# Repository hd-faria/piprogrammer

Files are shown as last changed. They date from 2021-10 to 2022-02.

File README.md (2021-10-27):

# piprogrammer
This hat was designed based on Wren's Pi400-Pico-Plate, but since I don't have a Pi400, just a Raspberry Pi 4 4GB, I needed to make some changes. Also added an extra button and a JST(Qwiic) connector, which is connected to floating header because I wanted the flexibility to move I2C. Also added a 50" JTAG/SWD header footprint in hopes that I can use the Pi4 to program target devices other than RP2040 based boards, I remember to have seem some adafruit/learn post on this kind of subject some time ago.

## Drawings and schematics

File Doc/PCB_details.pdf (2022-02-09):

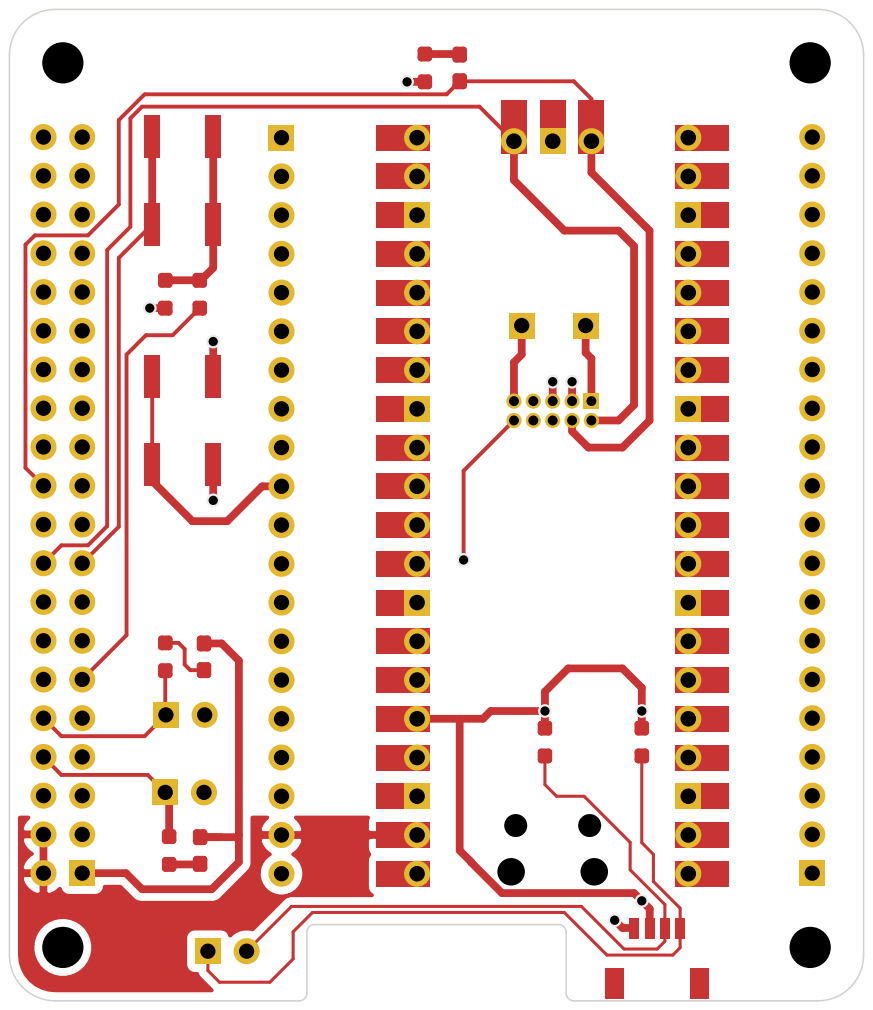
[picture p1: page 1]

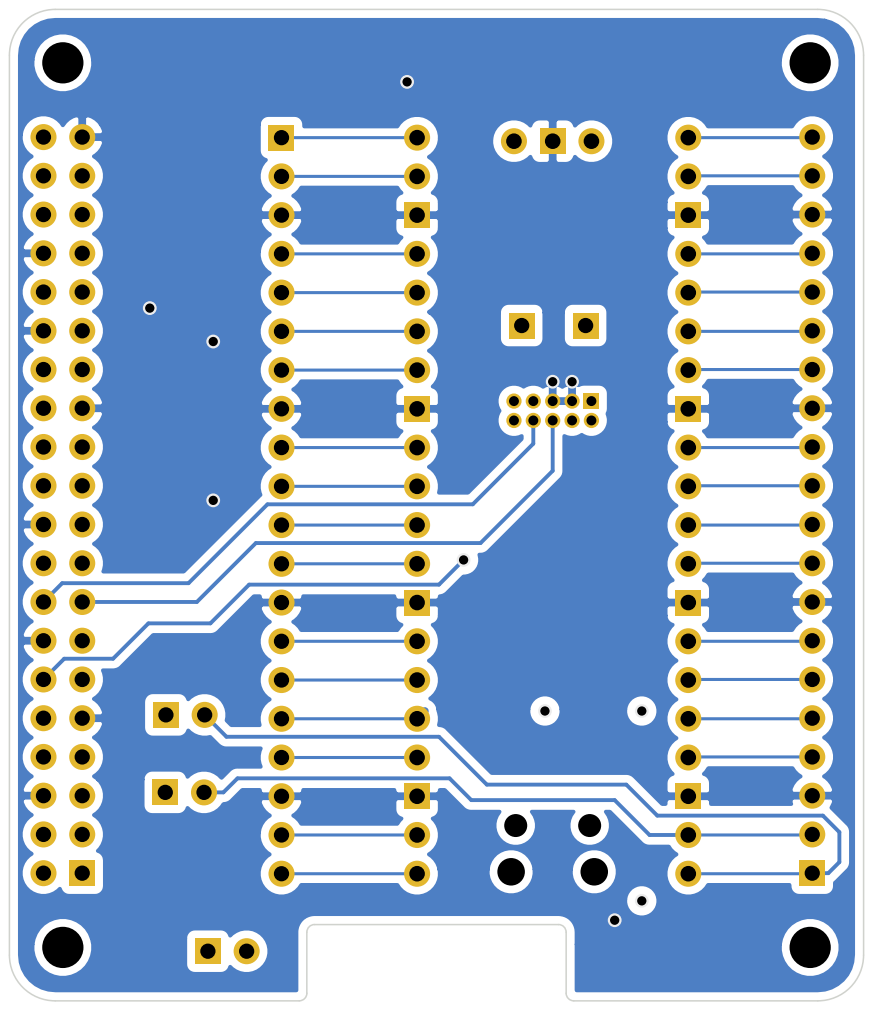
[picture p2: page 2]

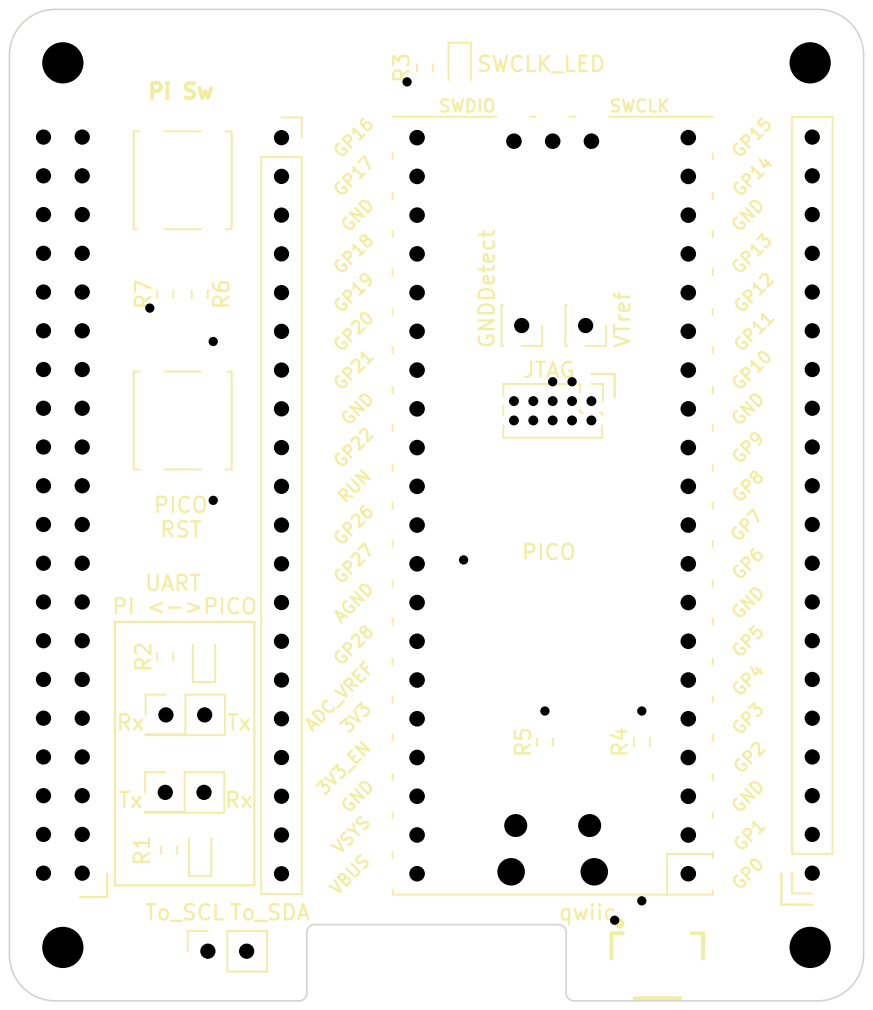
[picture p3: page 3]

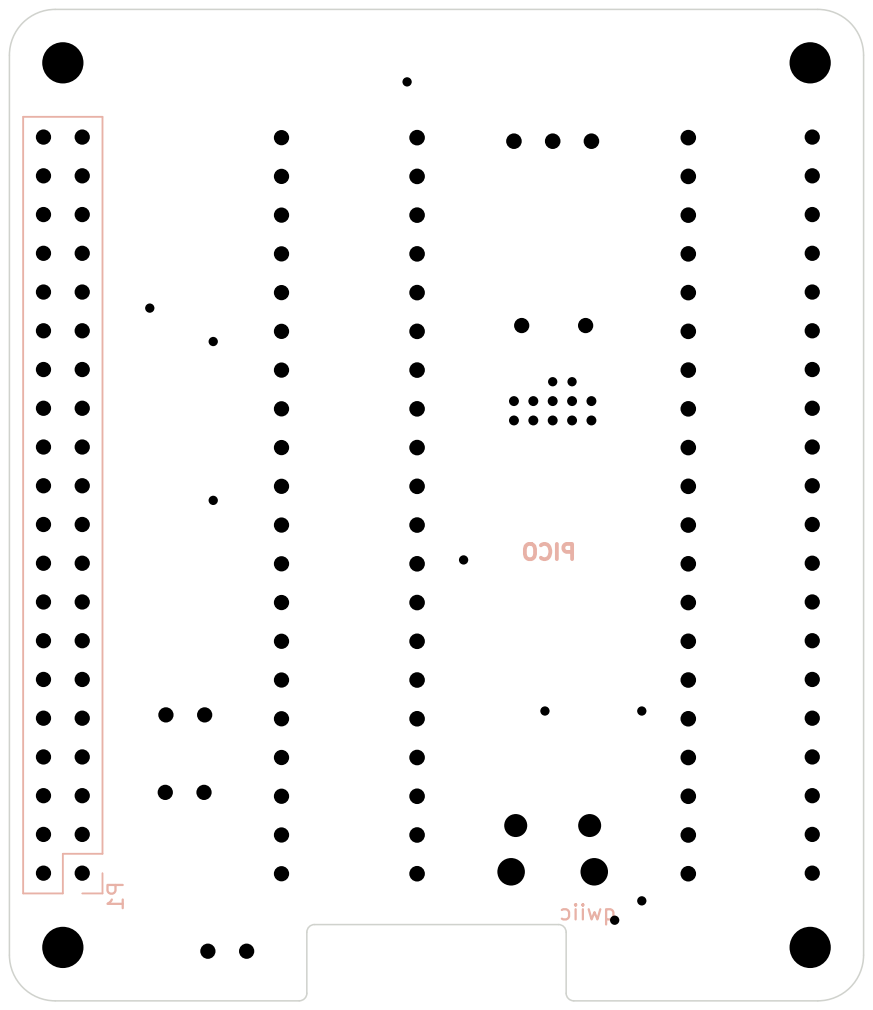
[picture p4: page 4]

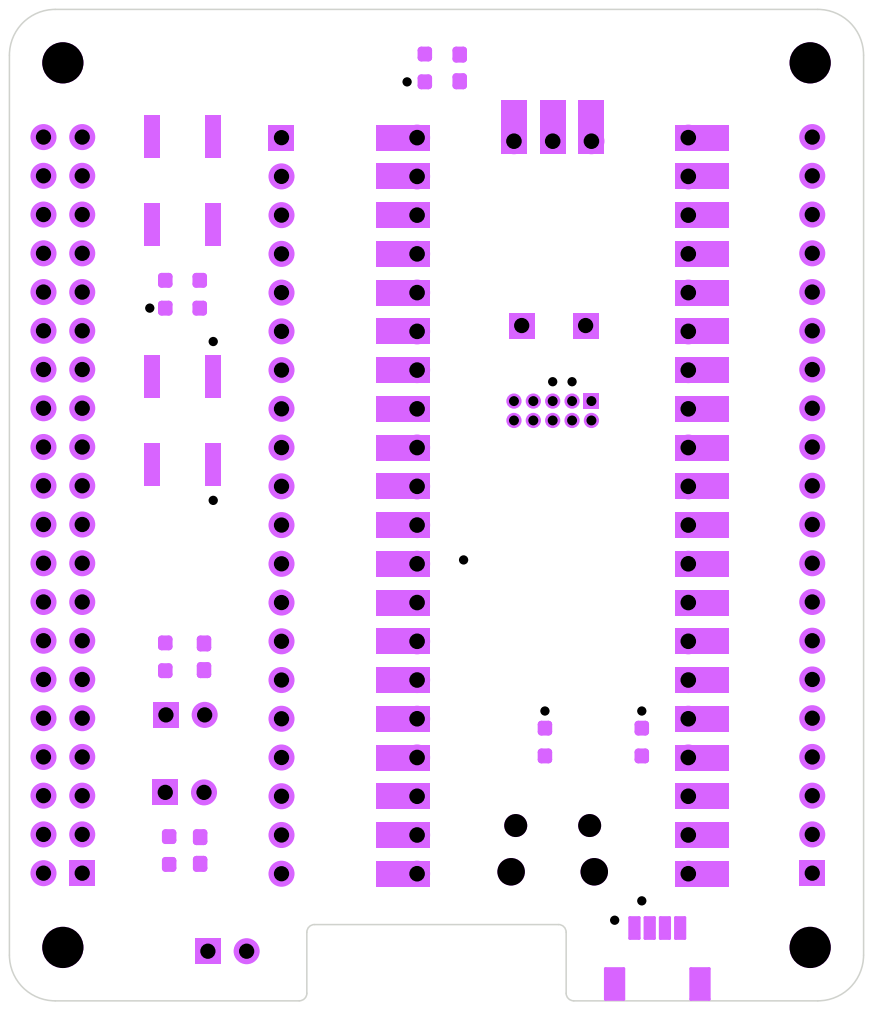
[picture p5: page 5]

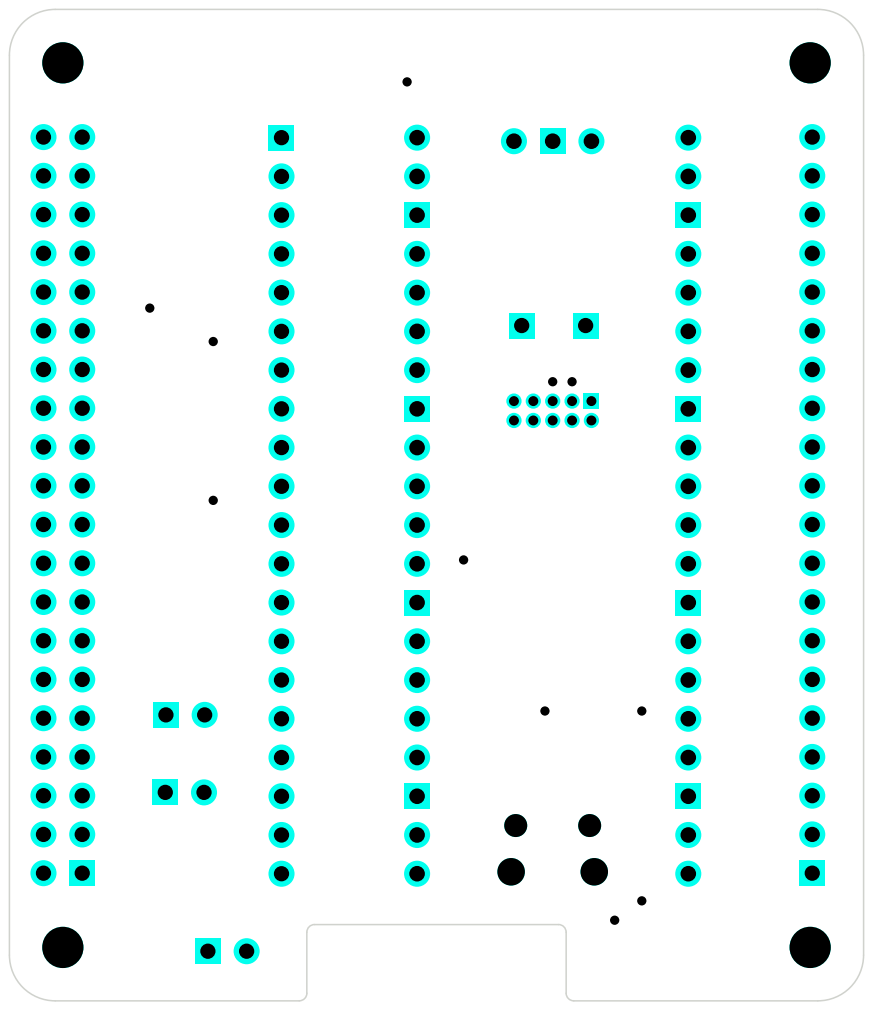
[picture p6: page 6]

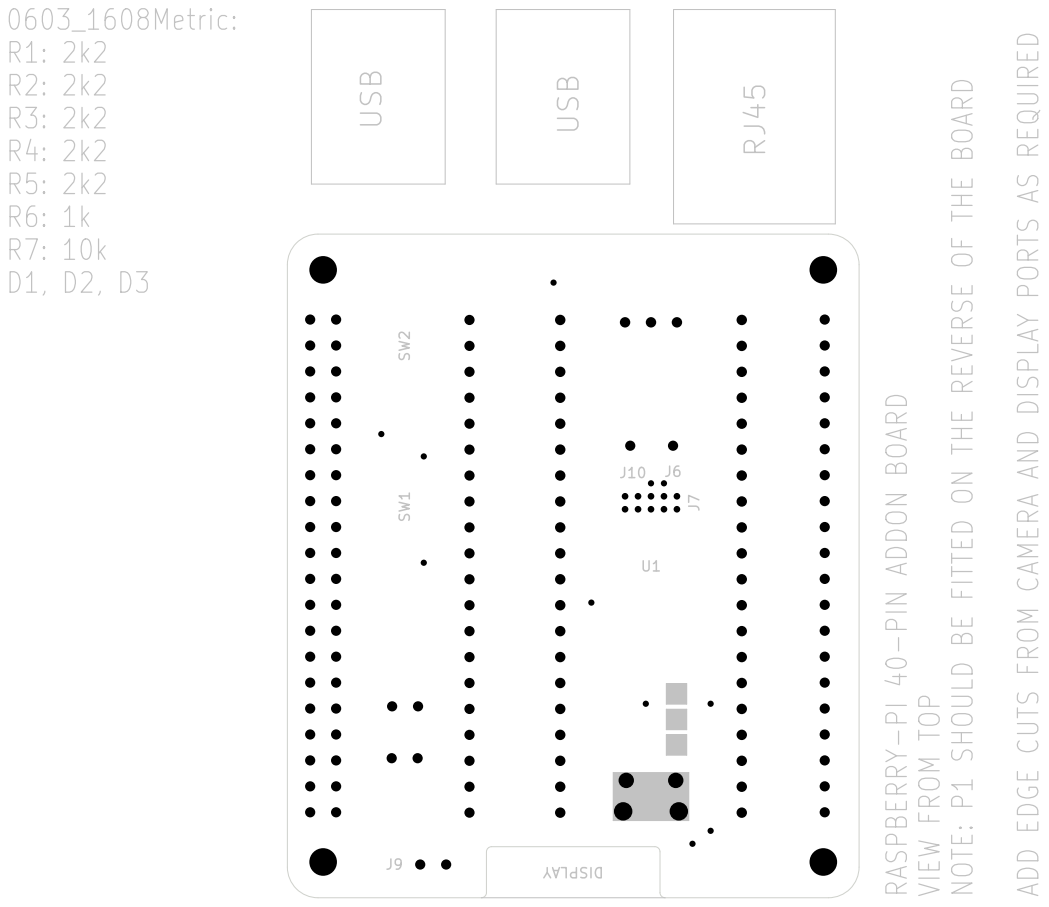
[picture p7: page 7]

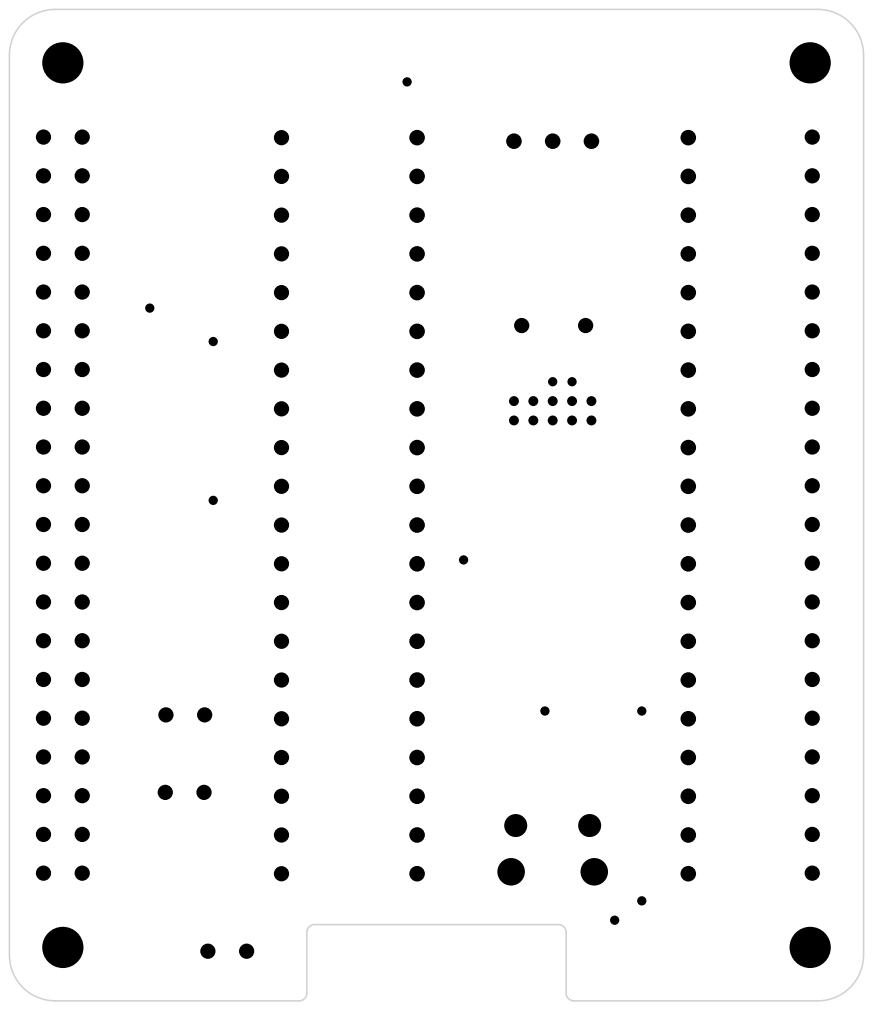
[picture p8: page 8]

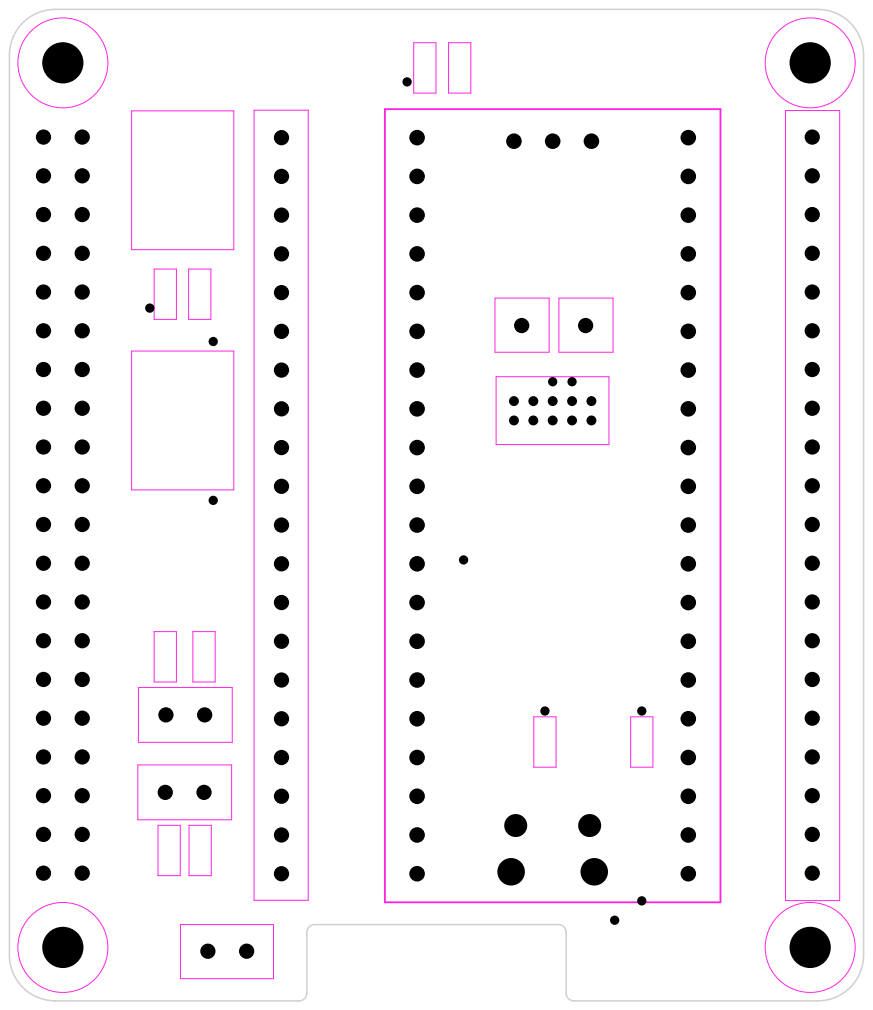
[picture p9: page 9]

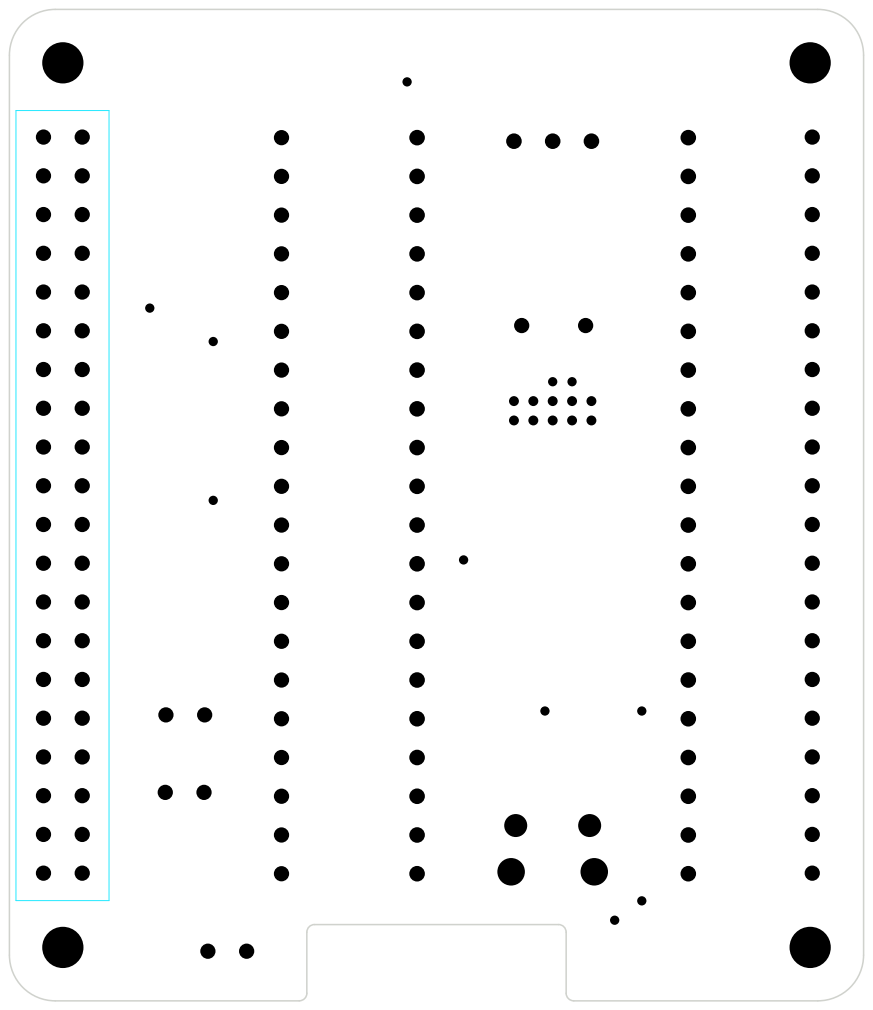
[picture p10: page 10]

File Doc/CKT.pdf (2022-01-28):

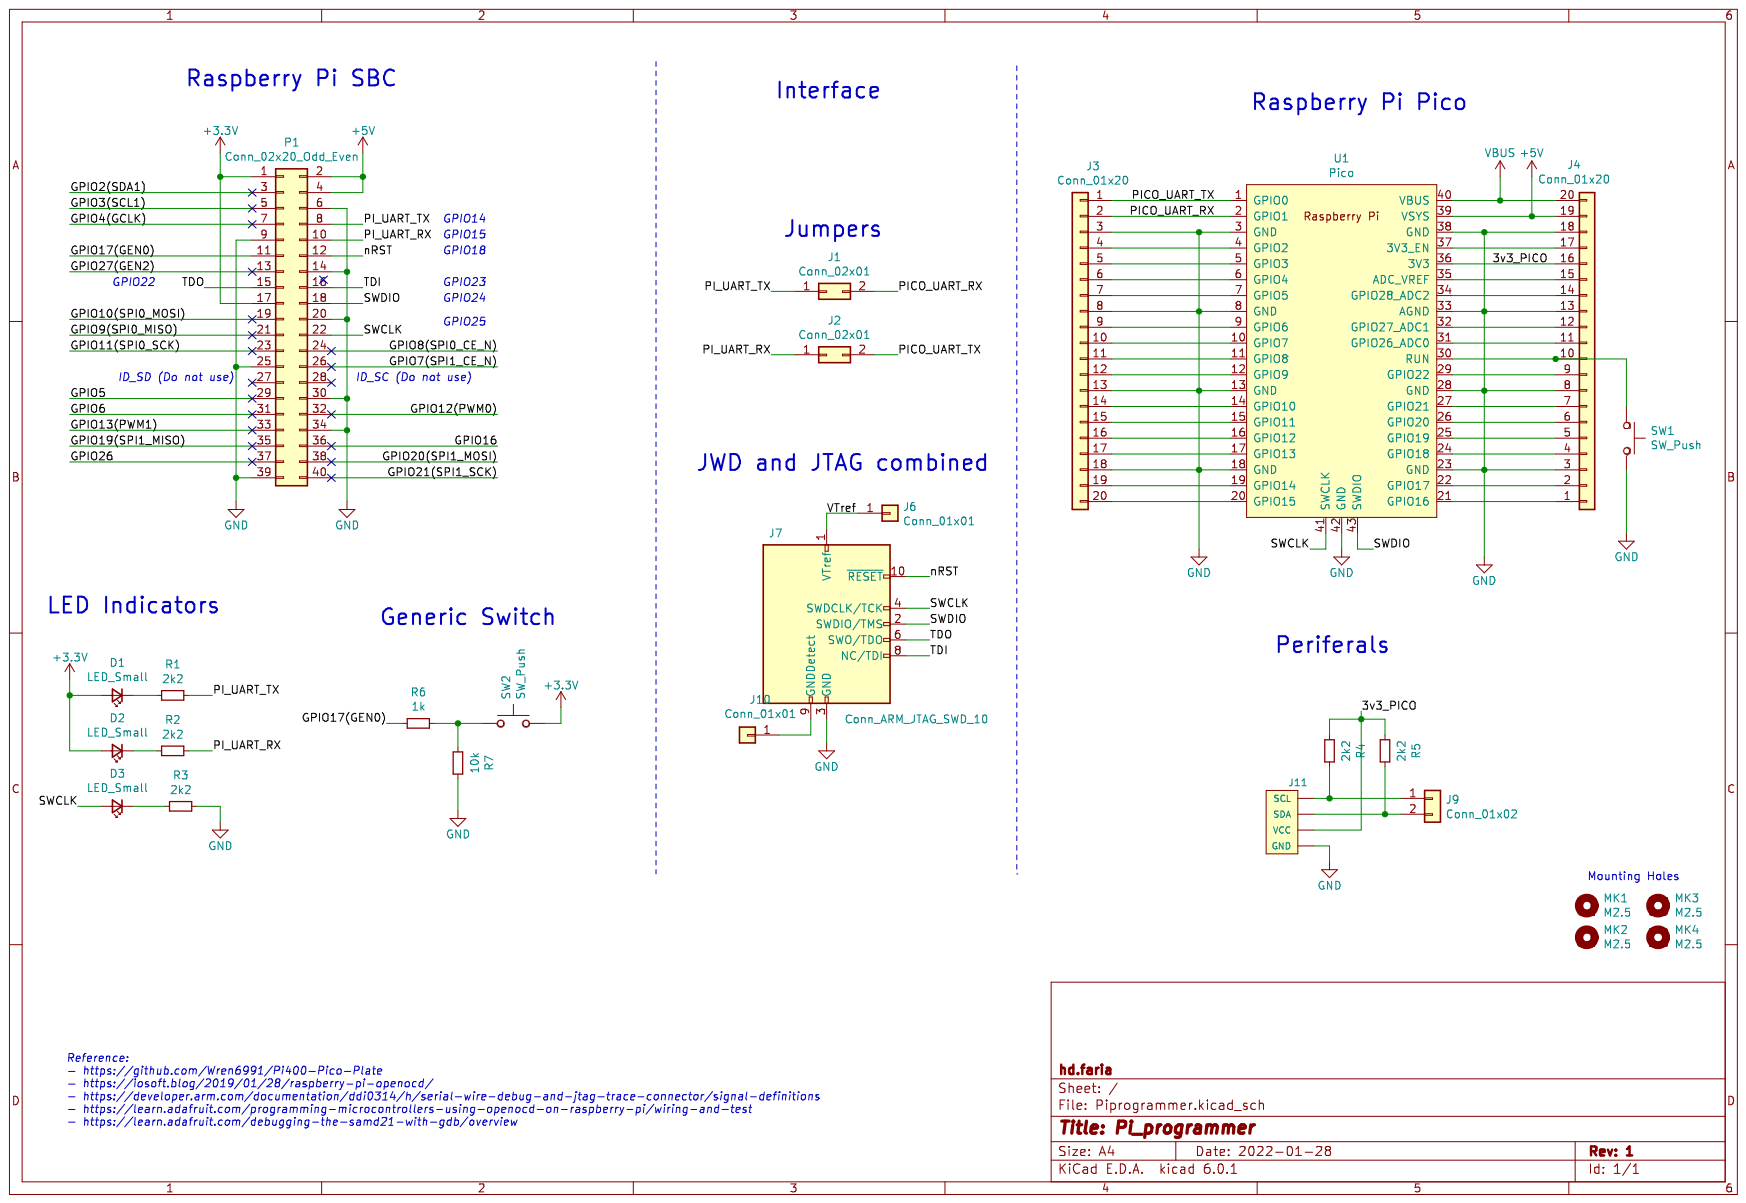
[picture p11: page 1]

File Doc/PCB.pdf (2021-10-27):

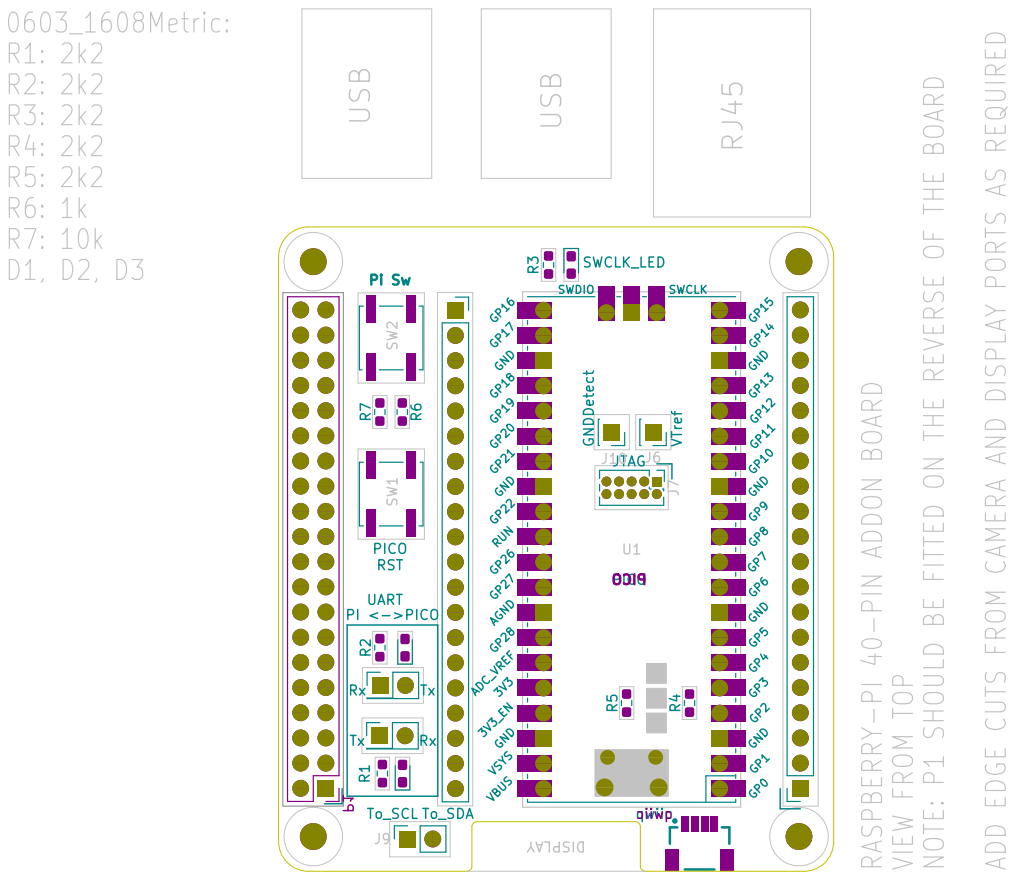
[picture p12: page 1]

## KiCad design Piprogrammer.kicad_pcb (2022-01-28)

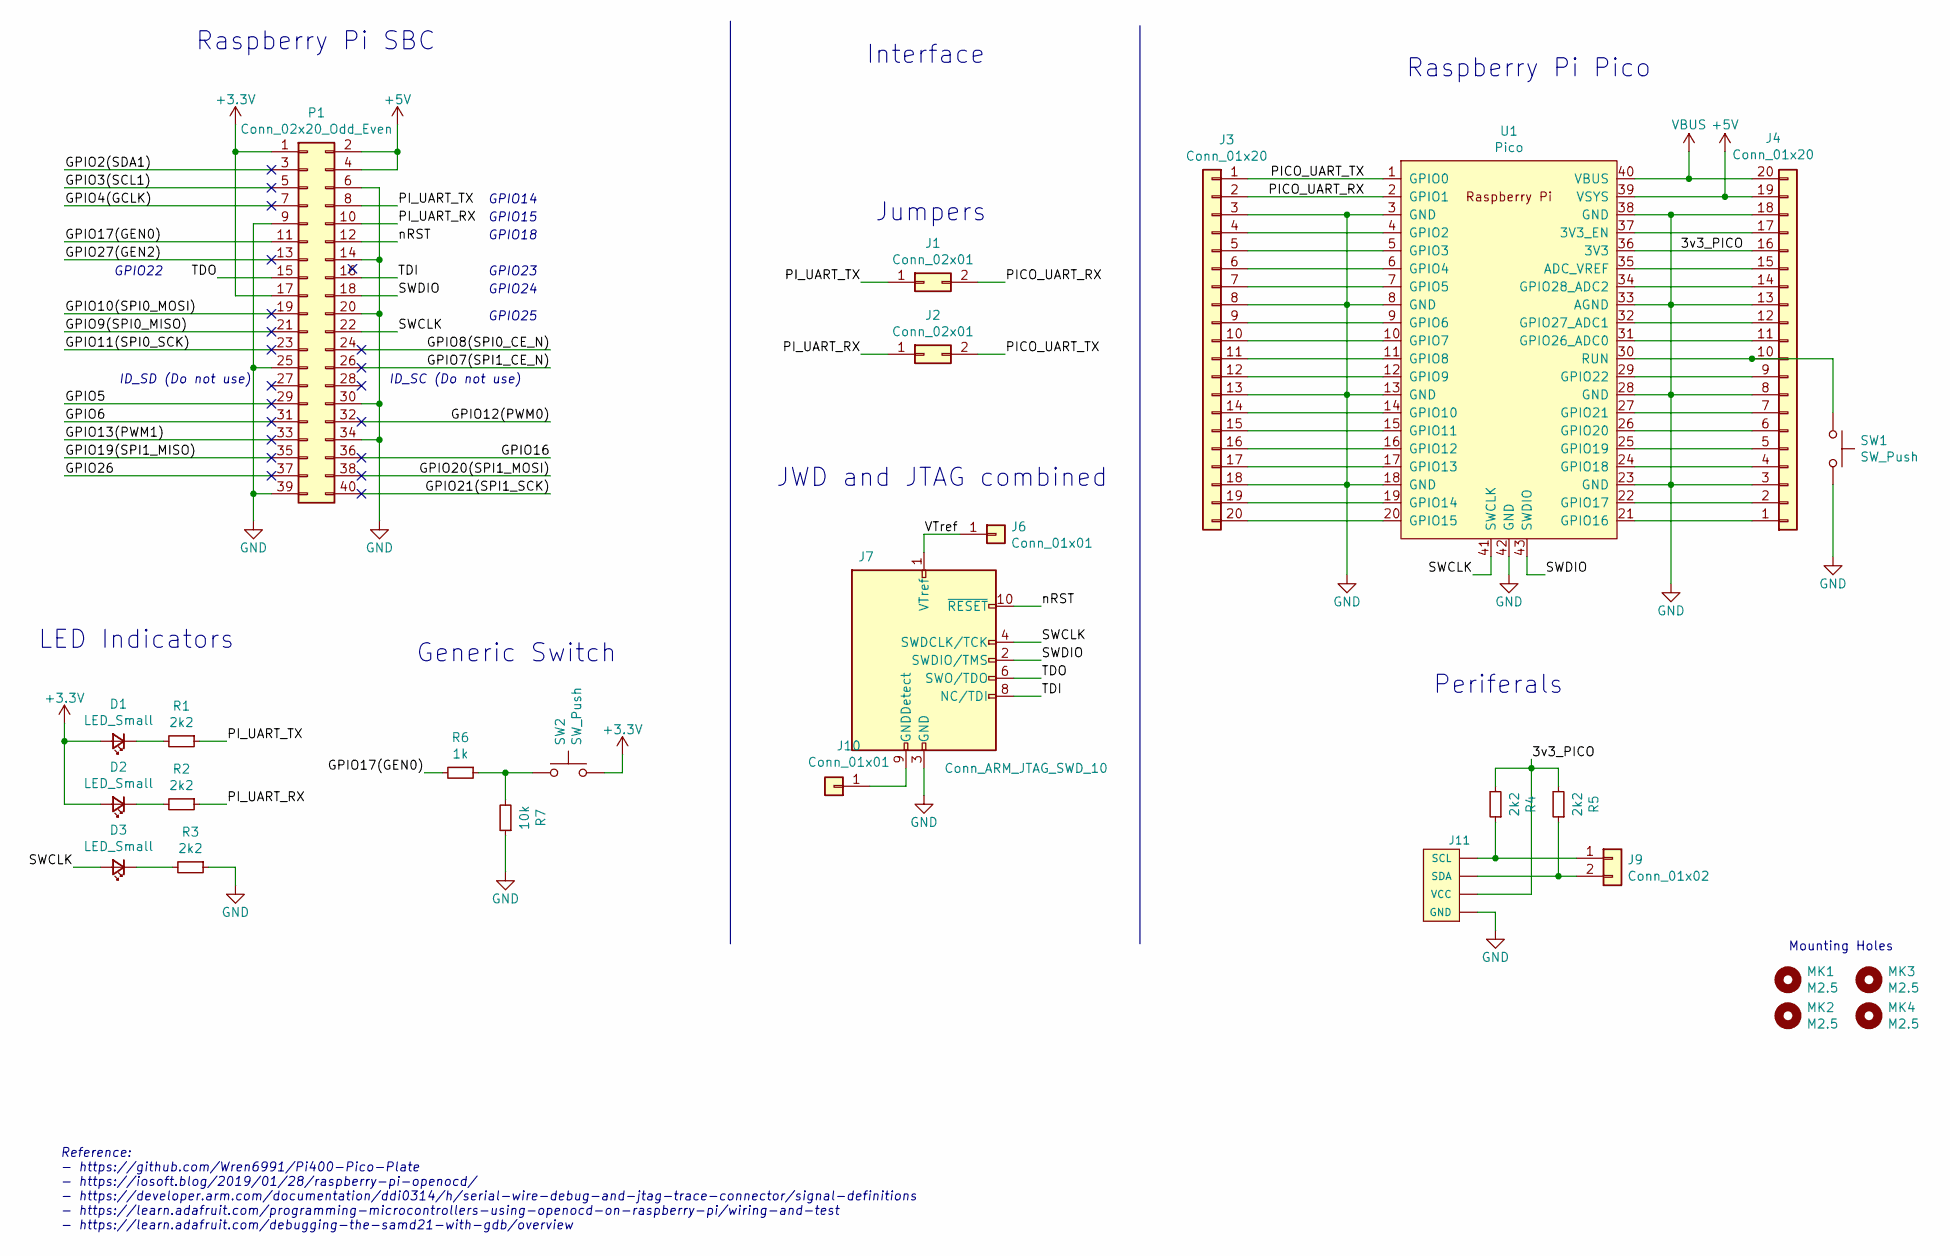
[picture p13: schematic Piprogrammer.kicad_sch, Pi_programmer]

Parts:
D1, D2, D3: LED_Small; LED_0603_1608Metric_Pad1.05x0.95mm_HandSolder
J1, J2: Conn_02x01; PinHeader_2x01_P2.54mm_Vertical
J3, J4: Conn_01x20; PinSocket_1x20_P2.54mm_Vertical
J6, J10: Conn_01x01; PinSocket_1x01_P2.54mm_Vertical
J7: Conn_ARM_JTAG_SWD_10; PinHeader_2x05_P1.27mm_Vertical
J9: Conn_01x02; PinSocket_1x02_P2.54mm_Vertical
J11: QWIIC_CONNECTORJS-1MM; 1X04_1MM_RA
MK1, MK2, MK3, MK4: M2.5; MountingHole_2-5mm
P1: Conn_02x20_Odd_Even; Socket_Strip_Straight_2x20
R1, R2, R3, R4, R5: 2k2; R_0603_1608Metric_Pad0.98x0.95mm_HandSolder
R6: 1k; R_0603_1608Metric_Pad0.98x0.95mm_HandSolder
R7: 10k; R_0603_1608Metric_Pad0.98x0.95mm_HandSolder
SW1, SW2: SW_Push; SW_Push_1P1T_NO_CK_KSC6xxJ
U1: Pico; RPi_Pico_SMD_TH

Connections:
+3V3: D1.2 (A), D2.2 (A), P1.1, P1.17, SW2.2
+5V: J4.19, P1.2, P1.4, U1.39 (VSYS)
/3v3_PICO: J4.16, J11.2 (VCC), R4.2, R5.2, U1.36 (3V3)
/GPIO2(SDA1): P1.3
/GPIO3(SCL1): P1.5
/GPIO4(GCLK): P1.7
/GPIO5: P1.29
/GPIO6: P1.31
/GPIO7(SPI1_CE_N): P1.26
/GPIO8(SPI0_CE_N): P1.24
/GPIO9(SPI0_MISO): P1.21
/GPIO10(SPI0_MOSI): P1.19
/GPIO11(SPI0_SCK): P1.23
/GPIO12(PWM0): P1.32
/GPIO13(PWM1): P1.33
/GPIO16: P1.36
/GPIO17(GEN0): P1.11, R6.2
/GPIO19(SPI1_MISO): P1.35
/GPIO20(SPI1_MOSI): P1.38
/GPIO21(SPI1_SCK): P1.40
/GPIO26: P1.37
/GPIO27(GEN2): P1.13
/PICO_UART_RX: J1.2, J3.2, U1.2 (GPIO1)
/PICO_UART_TX: J2.2, J3.1, U1.1 (GPIO0)
/PI_UART_RX: J2.1, P1.10, R2.1
/PI_UART_TX: J1.1, P1.8, R1.1
/SWCLK: D3.2 (A), J7.4 (SWDCLK/TCK), P1.22, U1.41 (SWCLK)
/SWDIO: J7.2 (SWDIO/TMS), P1.18, U1.43 (SWDIO)
/TDI: J7.8 (NC/TDI), P1.16
/TDO: J7.6 (SWO/TDO), P1.15
/VTref: J6.1, J7.1 (VTref)
/nRST: J7.10 (~RESET), P1.12
GND: J3.3, J3.8, J3.13, J3.18, J4.3, J4.8, J4.13, J4.18, J7.3 (GND), J7.5 (GND), J11.1 (GND), P1.6, P1.9, P1.14, P1.20, P1.25, P1.30, P1.34, P1.39, R3.1, R7.1, SW1.2, U1.3 (GND), U1.8 (GND), U1.13 (GND), U1.18 (GND), U1.23 (GND), U1.28 (GND), U1.33 (AGND), U1.38 (GND), U1.42 (GND)
unnamed: D1.1 (K), R1.2
unnamed: D2.1 (K), R2.2
unnamed: D3.1 (K), R3.2
unnamed: J3.4, U1.4 (GPIO2)
unnamed: J3.5, U1.5 (GPIO3)
unnamed: J3.6, U1.6 (GPIO4)
unnamed: J3.7, U1.7 (GPIO5)
unnamed: J3.9, U1.9 (GPIO6)
unnamed: J3.10, U1.10 (GPIO7)
unnamed: J3.11, U1.11 (GPIO8)
unnamed: J3.12, U1.12 (GPIO9)
unnamed: J3.14, U1.14 (GPIO10)
unnamed: J3.15, U1.15 (GPIO11)
unnamed: J3.16, U1.16 (GPIO12)
unnamed: J3.17, U1.17 (GPIO13)
unnamed: J3.19, U1.19 (GPIO14)
unnamed: J3.20, U1.20 (GPIO15)
unnamed: J4.1, U1.21 (GPIO16)
unnamed: J4.2, U1.22 (GPIO17)
unnamed: J4.4, U1.24 (GPIO18)
unnamed: J4.5, U1.25 (GPIO19)
unnamed: J4.6, U1.26 (GPIO20)
unnamed: J4.7, U1.27 (GPIO21)
unnamed: J4.9, U1.29 (GPIO22)
unnamed: J4.10, SW1.1, U1.30 (RUN)
unnamed: J4.11, U1.31 (GPIO26_ADC0)
unnamed: J4.12, U1.32 (GPIO27_ADC1)
unnamed: J4.14, U1.34 (GPIO28_ADC2)
unnamed: J4.15, U1.35 (ADC_VREF)
unnamed: J4.17, U1.37 (3V3_EN)
unnamed: J7.9 (GNDDetect), J10.1
unnamed: J9.2, J11.3 (SDA), R5.1
unnamed: J9.1, J11.4 (SCL), R4.1
unnamed: R6.1, R7.2, SW2.1
VBUS: J4.20, U1.40 (VBUS)

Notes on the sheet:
GPIO22
LED Indicators
ID_SD (Do not use)
GPIO24
Raspberry Pi SBC
GPIO23
Generic Switch
GPIO25
GPIO14
Mounting Holes
Jumpers
Raspberry Pi Pico
Interface
GPIO18
Reference: - https://github.com/Wren6991/Pi400-Pico-Plate - https://iosoft.blog/2019/01/28/raspberry-pi-openocd/ - https://developer.arm.com/documentation/ddi0314/h/serial-wire-debug-and-jtag-trace-connector/signal-definitions - https://learn.adafruit.com/programming-microcontrollers-using-openocd-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
Periferals
ID_SC (Do not use)
GPIO15
JWD and JTAG combined

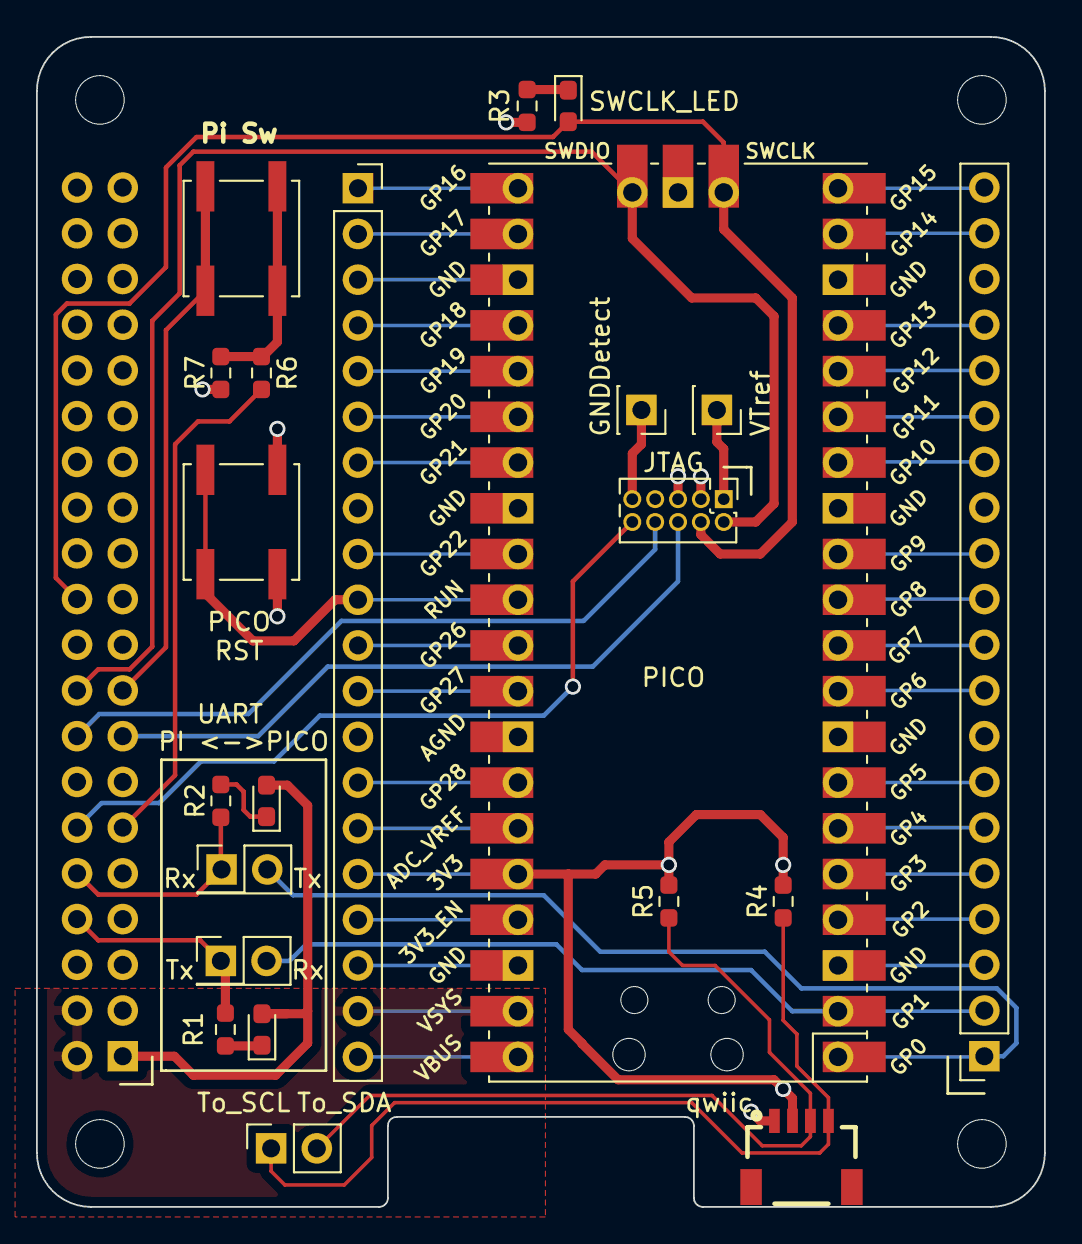
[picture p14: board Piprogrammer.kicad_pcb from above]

Board: 2 copper layers, 56.0 x 65.0 mm, 27 parts (1 on the bottom side), 50 nets.

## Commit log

2021-10-27 add current content
    [Piprogrammer-B_Cu.gbl, Piprogrammer-B_Mask.gbs, Piprogrammer-B_Paste.gbp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]
2022-01-28 minor update em schematics presentation, update to kicad 6
    [Piprogrammer.kicad_pcb, Piprogrammer.kicad_sch]
2022-02-09 add pcb layers pdf
